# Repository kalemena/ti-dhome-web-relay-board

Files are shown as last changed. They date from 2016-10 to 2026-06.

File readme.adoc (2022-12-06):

= Web Relay Board
:toc:
:hardbreaks:

ifdef::env-github[]
:imagesdir: /
endif::[]

== Description

This project is an Open Source / Open Hardware minimal approach to build a Web Relay Board.
This Web Relay Board:

- allows to connect 16 devices allowing to switch on/off Main Power
- has temperature / humidity sensor
- captures Téléinfo (France Electricity provider serial consumption data)
- has REST API
- has Web Socket API

WARNING: Caution with 230v. Do not use high current.

Check more info in link:http://kalemena.github.io/ti-dhome-web-relay-board/[Details].

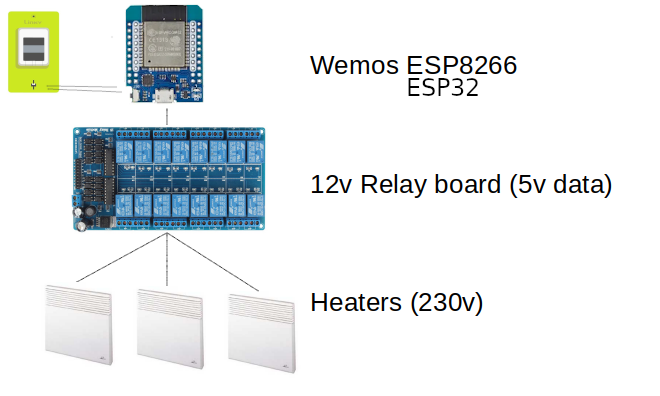
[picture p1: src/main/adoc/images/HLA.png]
HLA


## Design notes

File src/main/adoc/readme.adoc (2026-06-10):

:toc:

ifdef::env-github[]
:imagesdir: /src/main/adoc
endif::[]

= Web Relay Board

== Description

This project is an Open Source / Open Hardware minimal approach to build a Web Relay Board.

This Web Relay Board:

- allows to connect 16 devices allowing to switch on/off Main Power
- has temperature / humidity sensor
- captures Téléinfo (France Electricity provider serial consumption data)
- has REST API
- has Web Socket API

WARNING: Caution with 230v. Do not use high current.

The Web Relay board uses HTTP/REST API as interface.
Additionaly, simple Web UI is implemented on top of the REST API.

In practice, the Web Relay is used to manage electric heaters with data wire named link:http://www.planete-domotique.com/blog/2012/01/05/piloter-un-radiateur-grace-a-son-fil-pilote/[fil pilote] which is 230v at very low current. The heaters are ochestrated through Node-Red.

NOTE: This project is part of a wider link:https://github.com/kalemena/ti-dhome[TiDhome Home Automation] project.

.Integration WebRelay and Teleinfo
HLA

.Integration Teleinfo
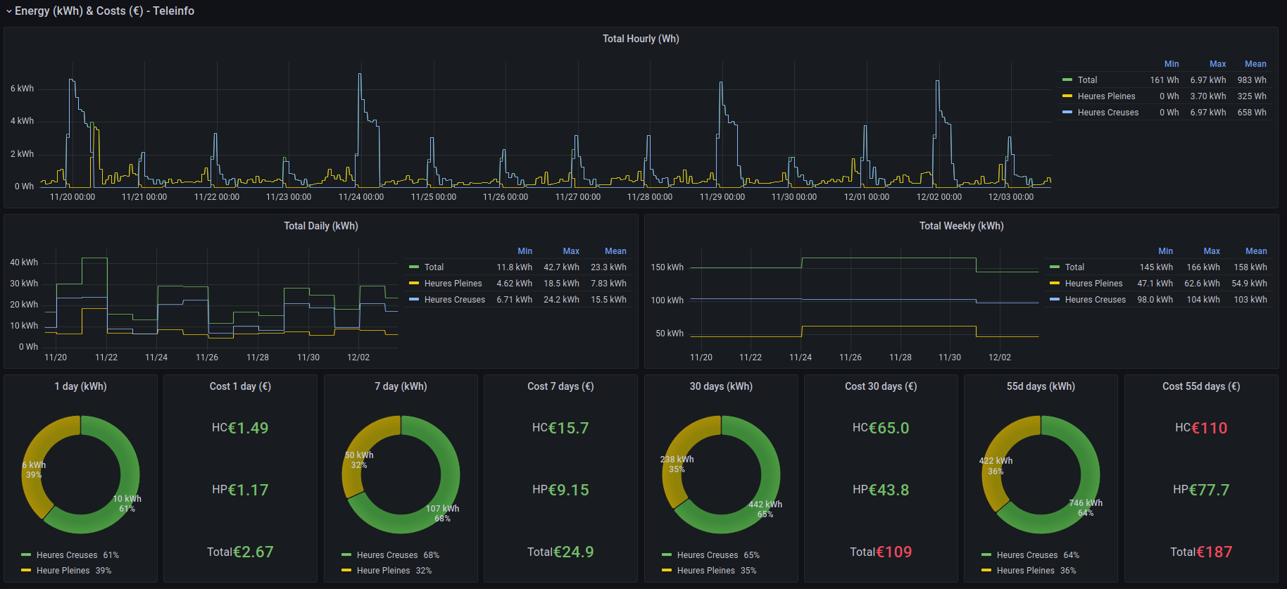
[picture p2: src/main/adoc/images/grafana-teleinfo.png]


NOTE: Above is an example of a dashboard created as part of Ti-Dhome project and using mostly Teleinfo data produces by the module in this repo, published to Node-Red through Web Sockets and inserted in Prometheus for Grafana use.

== Specifications

- 16 relays for 230v main current
- Wifi
- link:#api[REST API]
- WebSockets
- Reads EDF Téléinfo (France power consumption of the home as serial stream of data)
- Reads room temperature and humidity
- Simple web UI

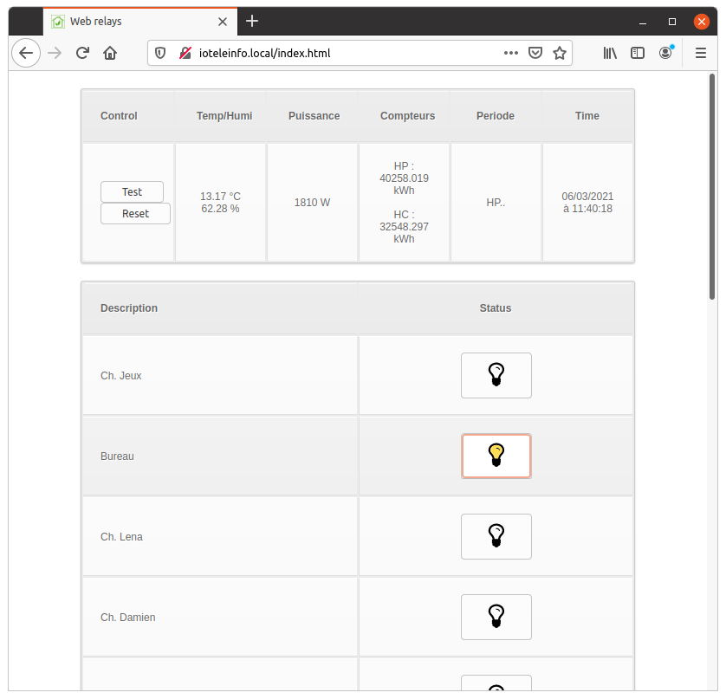
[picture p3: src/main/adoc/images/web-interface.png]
Web Relays UI


== PCB

PCB available at link:{giturl}/src/main/gerber[here]

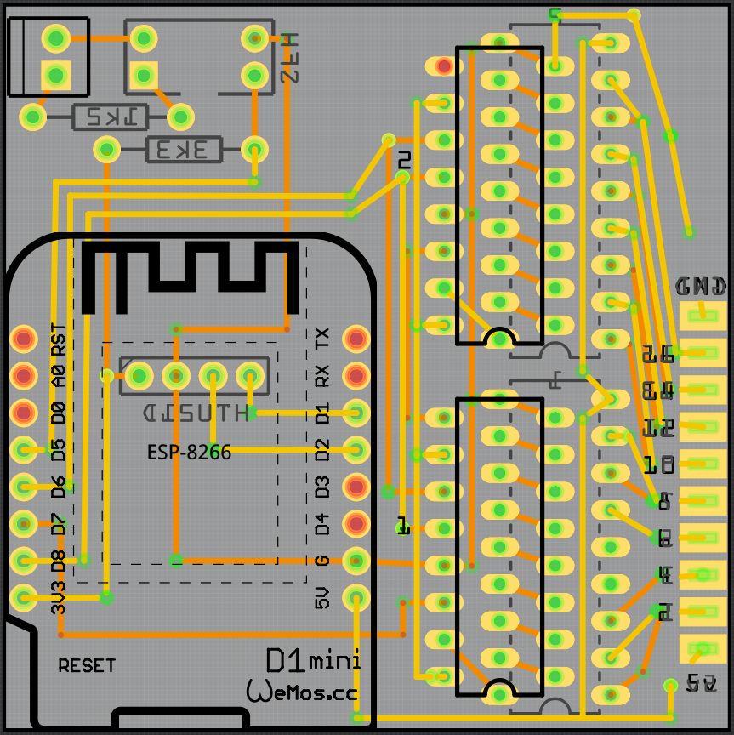
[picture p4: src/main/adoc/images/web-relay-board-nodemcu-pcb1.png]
PCB Board ESP8266 WeMos


PCB was printed at link:https://www.dfrobot.com/index.php?route=product/pcb&product_id=1351[DFRobot]

== Integration in Electric panel

Here is an integration of freshly solder PCB into electric panel:

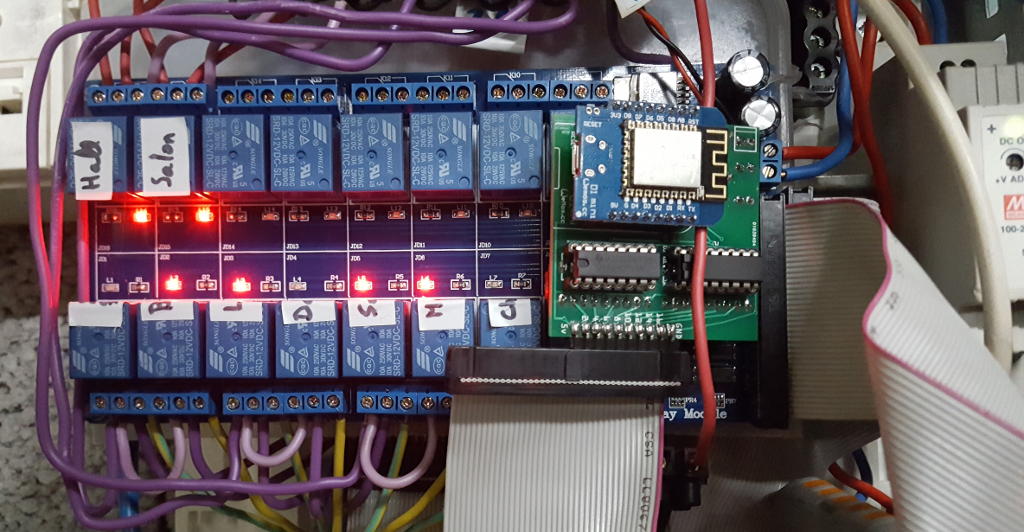
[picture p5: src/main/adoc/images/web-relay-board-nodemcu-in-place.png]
Electric panel Web Relays


== BOM

Here is list of items to purchase:

.BOM
[width="80%",cols="3,^2,10",options="header"]
|=========================================================
|Component |Price |Comment

| SainSmart 16 relays |~ 12€ | 16 relays 12v with 5v data triggers

| Wemos ESP8266 or ESP32 with (Wemos-clone pin layout)] |~ 4€ | 

| 2x 74HC595 |~ 0.2€ | Shift Register IC DIP-16 Texas (sold by 20)

| 2x ULN2803 |~ 0.12€ | (sold by 20)

| Optional (for Teleinfo and Temperature sensor | |

| SFH6206 | < 1€ | Optocoupler for Teleinfo
| 4.7k resistor | | For Teleinfo
| HTU21D | < 4€ | Temperature sensor

| *Total* | ~ 20€ |

|=========================================================

// GitHub - api
ifdef::env-github[]

link:api.adoc[API page] describes sample queries.

endif::[]

// non-GitHub - api
ifndef::env-github[]

:leveloffset: +1

include::api.adoc[API page]

:leveloffset: -1

endif::[]

== TODO

- create 3D-printed plastic box

// GitHub - iterations
ifdef::env-github[]

== Iterations

link:iterations.adoc[Here] are described step by step experiments to reach final product.

endif::[]

// non-GitHub - iterations
ifndef::env-github[]

:leveloffset: +1

include::iterations.adoc[Iterations page]

:leveloffset: -1

endif::[]

== Arduino CLI tips

```bash
% export BOARD=esp32:esp32:d1_mini32
% export SKETCH=./src/main/sketches/esp32-01-led/esp32-01-led.ino
% export PORT=/dev/cu.usbserial-110

% arduino-cli compile --fqbn ${BOARD} ${SKETCH} \
  && arduino-cli upload --fqbn ${BOARD} --port ${PORT} ${SKETCH}

% arduino-cli monitor --port ${PORT} --config baudrate=115200
```

== Links

Other interesting links for more specific heater oriented board:

* link:https://github.com/tducret/programmateur-fil-pilote-wifi/tree/master/Mat%C3%A9riel/1.3/Tutoriel[Programmateur-fil-pilote-wifi]

* link:https://air.imag.fr/index.php/Developing_IoT_Mashups_with_Docker,_MQTT,_Node-RED,_InfluxDB,_Grafana[IoT Mashups]

* link:https://telefab.fr/2013/11/10/controle-a-distance-des-radiateurs/[Contrôle à distance des radiateurs]

.Integration with Node-RED
* link:https://github.com/DenisMtfl/node-red-contrib-dynamic-thermostat[Node-Red Thermostat]
* link:https://github.com/naimo84/node-red-contrib-ical-events[iCal Events] or link:https://github.com/tyrrellsystems/node-red-contrib-simple-weekly-scheduler[Weekly scheduler]

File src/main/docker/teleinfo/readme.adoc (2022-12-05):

= Example - Teleinfo
:toc:
:hardbreaks:

This folder contains a sample demoing how to graph Teleinfo data.

Teleinfo is France EDF metrics of your home power consumption.

There are several types of information provided by Teleinfo:

- Live power: 
PAPP, etc

- Historical: 
Based on indexes, energy can be easily computed.
This however might depend on High/Low hours costs.
Costs is a simple computation of counter rate, multiplied by H/L costs.

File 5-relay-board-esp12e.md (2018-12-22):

## 5 - ESP8266 - 12E

Switch from NodeMCU to ESP12.

### Wiring

### Resources

http://arduino-er.blogspot.fr/2015/05/fit-esp-12-breakout-board-on-breadboard.html

http://myrobotlab.org/content/esp8266-12-series-wifi-modules-update-out-lua-arduino-ide

http://www.kloppenborg.net/blog/microcontrollers/2016/08/02/getting-started-with-the-esp8266

| NodeMCU | 74HC595 | Comment |
| --- |:---:|:---:|
| gpio13 (D7) | pin 14 | data |
| gpio14 (D5) | pin 11 | clock (both 74HC595) |
| gpio15 (D8) | pin 12 | latch (both 74HC595) |

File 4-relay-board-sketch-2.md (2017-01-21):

## 4 - Relay board sketch

[First sketch](3-relay-board-sketch.md) is not very efficient.

It only touched simple ESP8266 capability.

This iteration is about going deeper into the topic:
- host static files such as images or CSS files
- use the SPIFFS ~3MB flash storage
- better HTML rendering
- web sockets

### Steps

#### Un coup dans le 'SPIFFS'

To leverage most of the 4MB disk from ESP8266, install plugin:

[Arduino IDE SPIFFS plugin](https://github.com/esp8266/arduino-esp8266fs-plugin)

Usage is pretty simple:
- create subfolder from sketch folder named 'data'
- use Arduino IDE / Tools / ESP Sketch Data Upload
- this takes very long as it uploads ~ 3MB (no matter what)

#### Sketch details

The sketch can be found under [web-relay-advanced](sketches/esp8266-web-relay-advanced) folder.

This is a basic sketch from SPIFFS example, with addition of relay web services.

SPIFFS is used only to load SVG images to be displayed on URL /index.htm.

### Resources

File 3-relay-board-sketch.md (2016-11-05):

## 3 - Relay board sketch

Breadboard prototype done at [02 Relay Board Prototype](2-relay-board-prototype.md)

Now is time for a bit of coding.

### How-To

Here is the first [Basic sketch](sketches/esp8266-web-relay-wifi/esp8266-web-relay-wifi.ino)

Details of mathematics in next section.

Steps:
- Uploaded from Arduino IDE
- Open Arduino console
- This should log the URL with IP address to connect to Wifi device
- connect using browser to see the table where you can switch on and off the relays

### Mathematics

#### Binary computation

We have wired 16 outputs.

This in turns can be mapped to an integer from 0 to 65535.

In Arduino code, this means [__unsigned int__](https://www.arduino.cc/en/Reference/UnsignedInt).

Let's see what this means from [Byte mathematics](http://playground.arduino.cc/Code/BitMath#quickref)

```js
unsigned int relayState = 0;

// state of each relay (switchId is relay number from 0 to 15):
boolean switchState = ((relayState >> switchId) & 1);

// Set relay to 0:
relayState &= ~(1 << relayNb);

// Set relat to 1:
relayState |= (1 << relayNb);
```

#### 74HC595 - ShiftOut

The [74HC595 ShiftOut](https://www.arduino.cc/en/Reference/ShiftOut) states that it is 8 bit and requires two steps operation to shift bits.

```js
// Value is anything between 0 to 65535 representing 16 bits of data I/Os
void switchRelay(int value) 
{
   // take the latchPin low:
   digitalWrite(latchPin, LOW);

   // shift out the highbyte
   shiftOut(dataPin, clockPin, MSBFIRST, (value >> 8));
   // shift out the lowbyte
   shiftOut(dataPin, clockPin, MSBFIRST, value);

   //take the latch pin high so the LEDs will light up:
   digitalWrite(latchPin, HIGH);
}
```

### Resources

- [74HC595 ShiftOut](https://www.arduino.cc/en/Reference/ShiftOut)

- [Byte mathematics](http://playground.arduino.cc/Code/BitMath#quickref)

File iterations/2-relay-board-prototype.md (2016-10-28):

# Breadboard relay board

Using Node MCU for Wifi, there are few remaining constraints:

- GPIOs are 3.3v and we need 5v: __ULN2803__ to the rescue
> ULN2803 is a Darlington array which can be used to translate from 3.3v digital outputs to 5v

- Not enough GPIOs: __74HC595__ to the rescue
> This components enables use of 3 GPIOs to be used in serial protocol to handle in our case the 16 outputs requires for relay board

Photo (:bell: only relay 8 to 15):

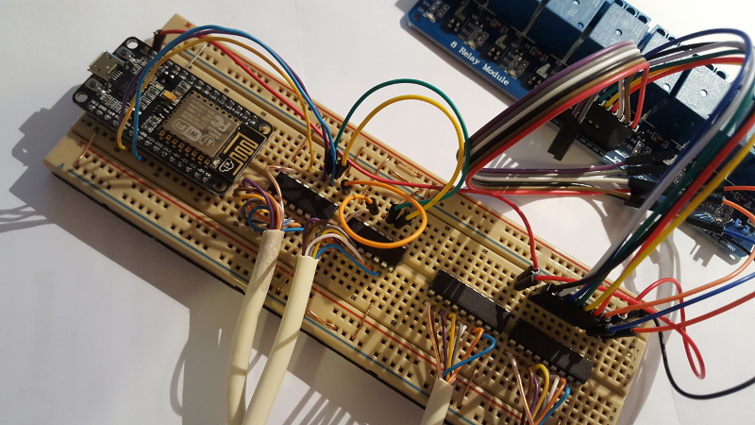
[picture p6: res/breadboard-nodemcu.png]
Breadboard NodeMCU


Fritzing picture:

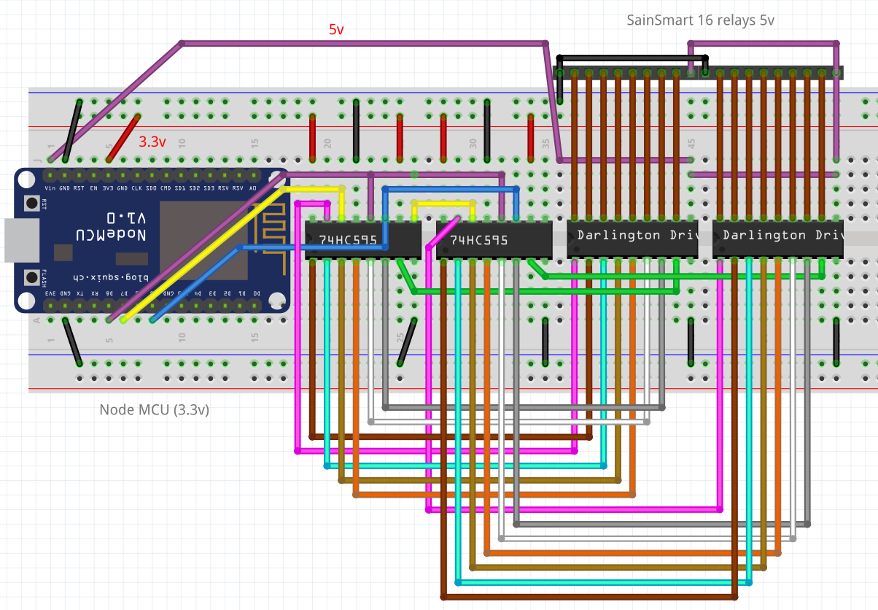
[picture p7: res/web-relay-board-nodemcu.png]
Breadboard NodeMCU


# Procedure

Few more details

## 74HC595

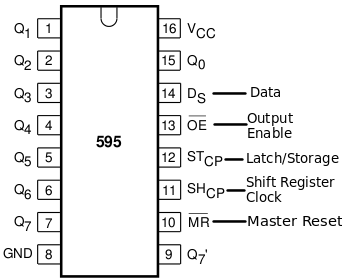
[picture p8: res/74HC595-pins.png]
74HC595 pins


We will use 3 pins from Node MCU:

| NodeMCU | 74HC595 | Comment  |
| --- |:---:|:---:|
| gpio13 (D7) | pin 14 | data |
| gpio14 (D5) | pin 11 | clock (both 74HC595) |
| gpio15 (D8) | pin 12 | latch (both 74HC595) |

:bell: Ground and 3.3v plugged obviously.

:bell: 1st 74HC595 is connected to 2nd 74HC595 from pin 9 to pin 14.

__We now have 16 I/Os !__

## ULN2803

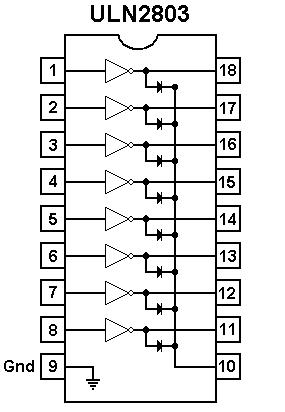
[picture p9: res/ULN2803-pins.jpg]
ULN2803 pins


| 74HC595 | ULN2803 | Comment  |
| --- |:---:|:---:|
| 8 | 9 | Ground |
| 5v (from power supply) | 10 | 5v :bell: not the 3.3v here!  |
| Q0 to Q7 | 1 to 8 | Outputs |

# Resources

- [ESP8266 8x8 matrix](http://www.instructables.com/id/NODEMCU-LUA-ESP8266-With-74HC595-LED-and-Matrix-Dr/step2/ESP8266-driving-dual-595s-with-8-x-8-Matrix/)

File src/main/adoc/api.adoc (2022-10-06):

= API
:toc:
:hardbreaks:

[TIP]
====
REST API and websocket API are returning same JSON structure data.

Additionaly, websocket will periodically push changing info such as other user relay switch, Téléinfo and temperature.
====

Below is API description with examples:

== GET /

Main HTML page display simple button and status:

Web Relays UI

== GET /status

[source, json]
----
$ curl http://ioteleinfo.local/status | jq .

{
  "system": {
    "chip-model": "ESP32-D0WDQ6",
    "chip-revision": 1,
    "chip-cores": 2,
    "chip-bluetooth": "/BT/BLE",
    "chip-id": "ABCDEFGH",
    "heap": 256412,
    "flash-size": 4,
    "flash-type": "external",
    "time-iso": "2021-02-06T11:44:37Z"
  },
  "sensors": {
    "temperature": 13.12,
    "humidity": 62.5
  },
  "relays": [
    {
      "description": "Ch. Jeux",
      "id": 0,
      "value": 0
    },
    {
      "description": "Bureau",
      "id": 1,
      "value": 0
    },
    ...
    {
      "description": "Hall",
      "id": 15,
      "value": 0
    }
  ],
  "teleinfo": {
    "ADCO": 123456789,
    "OPTARIF": "HC..",
    "ISOUSC": 45,
    "HCHC": 32548297,
    "HCHP": 40260054,
    "PTEC": "HP..",
    "IINST": 5,
    "IMAX": 90,
    "PAPP": 1100,
    "HHPHC": "A",
    "MOTDETAT": 0
  },
  "message": "status"
}
----

== GET /relays/set?id=X&value=Y

Specify id between 0 and 15:

[source, bash]
----
$ curl -v http://ioteleinfo.local/relays/set?id=1&value=-1
{
   "id": 1, "value":0
}
----

TIP: value is 0, 1 or -1 to switch blindly 

== GET /test

Triggers a cycle on/off on each of the relays, with 500ms in between on/off.
Useful to test the websocket reaction of Web UI.

[source, bash]
----
$ curl -v http://ioteleinfo.local/test
----

== WebSocket

Example at link:/src/main/sketches/esp32-10-web-relay-th-teleinfo/data/index.html[index.html]

.Time events (from time to time)
[source, json]
----
{
    "system":{
        "time":"1615034255"
    }
}
----

.Teleinfo events (when some field changes)
[source, json]
----
{
    "teleinfo":{
        "PAPP":"01140"
    }
}
----

.Temperature events (from time to time)
[source, json]
----
{
    "sensors":{
        "temperature":13.2,
        "humidity":62.75
    }
}
----

.Relays events (when a switch changes)
[source, json]
----
{
    "relays":[
        {"id":2,"value":1}
    ]
}
----

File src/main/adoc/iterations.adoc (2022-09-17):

= Iterations
:toc:

== 0 - Manual Setup ESP8266 board in Arduino IDE

NOTE: Since this tutorial was written, I made available a link:https://github.com/kalemena/iot-tools[Docker Arduino IDE]

The development uses simple Arduino IDE with ESP8266 libs.

Follow this guide to setup ESP8266 board in Arduino IDE: link:https://github.com/esp8266/Arduino[]

Documentation is here: link:http://esp8266.github.io/Arduino/versions/2.3.0/[]

=== Procedure

- Import ESP Board into Arduino IDE

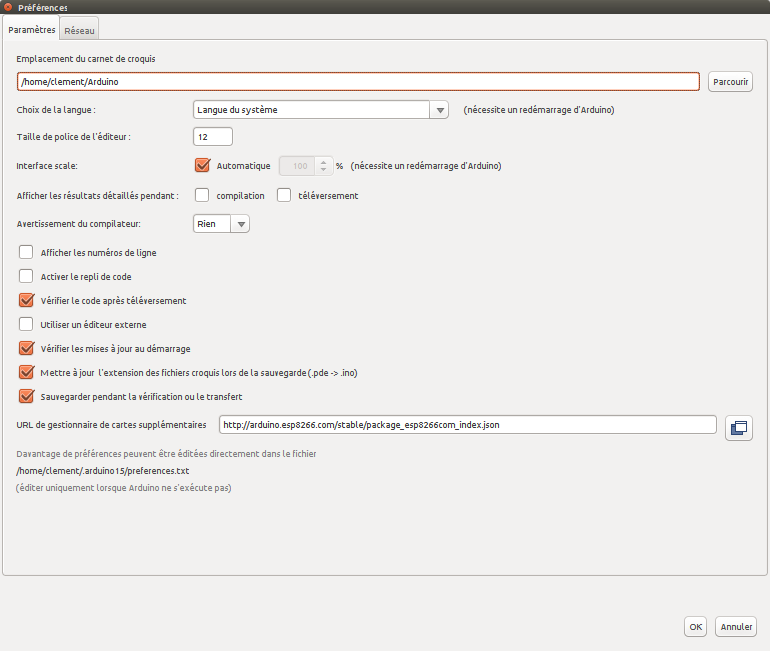
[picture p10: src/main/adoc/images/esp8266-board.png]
Import ESP Boards


- Load the Libraries for ESP8266

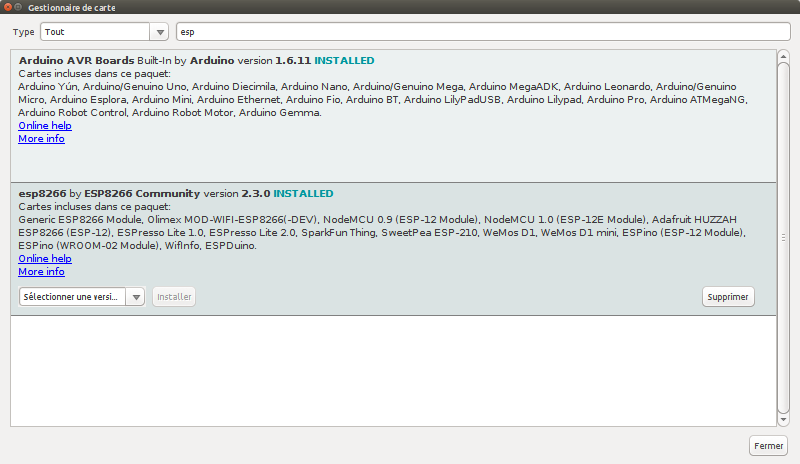
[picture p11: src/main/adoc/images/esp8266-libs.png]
Load ESP libraries


- Load sample *hello* app into NodeMCU

In Arduino IDE, select proper board, example:
- Tools/Cards/NodeMCU 1.0 board
- CPU 160 MHz
- <correct USB device>

Create sketch such as the link:{giturl}/src/main/sketches/esp8266-01-led/esp8266-01-led.ino[ESP8266 LED]

```js
void setup() {
  // initialize digital pin 2 as an output.
  pinMode(2, OUTPUT);
}

// the loop function runs over and over again forever
void loop() {
  digitalWrite(2, HIGH);   // turn the LED on (HIGH is the voltage level)
  delay(1000);              // wait for a second
  digitalWrite(2, LOW);    // turn the LED off by making the voltage LOW
  delay(1000);              // wait for a second
}
```

LED should blink as shown below:

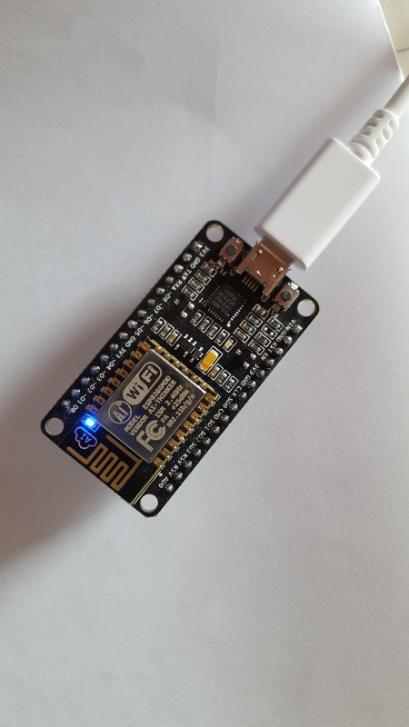
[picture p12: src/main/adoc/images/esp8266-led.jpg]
NodeMCU Blink


* Control a Wifi LED
** Upload sketch found at link:{giturl}/src/main/sketches/esp8266-02-led-wifi/esp8266-02-led-wifi.ino[ESP8266 LED WIFI] with changing Wifi network settings
** Open Serial Consoleon Arduino IDE
** Ensure from logs that NodeMCU connected to local Wifi
** Browse to IP address logged out
** Click on button to switch led On and Off

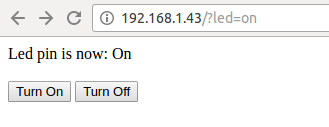
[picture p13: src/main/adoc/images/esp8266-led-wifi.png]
NodeMCU Blink Wifi


=== Resources

link:https://kalemena.github.io/iot-tools/[Arduino/ESP8266/ESP32 Pin Layout]

== 1 - Docker Setup ESP8266 board in Arduino IDE

See link:https://github.com/kalemena/iot-tools[Docker image kalemena:arduino:latest]

* check your tty device. e.g. /dev/ttyUSB2 and match it in *Makefile*
* open the Arduino IDE with:

[source,bash]
----
$ make arduino
----

== 2 - Breadboard relay board

Breadboard video

Using Node MCU for Wifi, there are few remaining constraints:

- GPIOs are 3.3v and we need 5v: *ULN2803* to the rescue
    
    > ULN2803 is a Darlington array which can be used to translate from 3.3v digital outputs to 5v

- Not enough GPIOs: *74HC595* to the rescue
    
    > This components enables use of 3 GPIOs to be used in serial protocol to handle in our case the 16 outputs requires for relay board

Photo (showing wired relay 8 to 15):

Breadboard NodeMCU

Fritzing picture:

Breadboard NodeMCU

=== Procedure

Few more details

==== 74HC595

74HC595 pins

We will use 3 pins from Node MCU:

.wiring 74HC595
[width="80%",cols="3,^2,10",options="header"]
|=========================================================
|NodeMCU |74HC595 |Comment

| gpio13 (D7)   | pin 14        | data
| gpio14 (D5)   | pin 11        | clock (both 74HC595) 
| gpio15 (D8)   | pin 12        | latch (both 74HC595) 

|=========================================================

IMPORTANT: Ground and 3.3v plugged obviously.

IMPORTANT: 1st 74HC595 is connected to 2nd 74HC595 from pin 9 to pin 14.

NOTE: *We now have 16 I/Os through 3 ESP8266 pins!*

==== ULN2803

ULN2803 pins

.wiring ULN2803
[width="80%",cols="3,^2,10",options="header"]
|=========================================================
|74HC595 |ULN2803 |Comment

| 8    | 9         | Ground
| 5v (from power supply)   | 10        | *5v not the 3.3v here!*
| Q0 to Q7   | 1 to 8        | Outputs

|=========================================================

=== Resources

- link:http://www.instructables.com/id/NODEMCU-LUA-ESP8266-With-74HC595-LED-and-Matrix-Dr/step2/ESP8266-driving-dual-595s-with-8-x-8-Matrix/[ESP8266 8x8 matrix]

== 3 - Relay board sketch

Now is time for a bit of coding.

=== How-To

Here is the first link:{giturl}/src/main/sketches/esp8266-04-web-relay-wifi/esp8266-04-web-relay-wifi.ino[Basic sketch]

Details of mathematics in next section.

Steps:

- Uploaded from Arduino IDE
- Open Arduino console
- This should log the URL with IP address to connect to Wifi device
- Connect using browser to see the table where you can switch on and off the relays

=== Mathematics

==== Binary computation

We have wired 16 outputs.

The outputs can be mapped to an integer from 0 to 65535.

In Arduino code, this means link:https://www.arduino.cc/en/Reference/UnsignedInt[__unsigned int__]

Let's see what this means from link:http://playground.arduino.cc/Code/BitMath#quickref[Byte mathematics]

```js
unsigned int relayState = 0;

// state of each relay (switchId is relay number from 0 to 15):
boolean switchState = ((relayState >> switchId) & 1);

// Set relay to 0:
relayState &= ~(1 << relayNb);

// Set relat to 1:
relayState |= (1 << relayNb);
```

==== 74HC595 - ShiftOut

The link:https://www.arduino.cc/en/Reference/ShiftOut[74HC595 ShiftOut] states that it is 8 bit and requires two steps operation to shift bits.

```js
// Value is anything between 0 to 65535 representing 16 bits of data I/Os
void switchRelay(int value) 
{
   // take the latchPin low:
   digitalWrite(latchPin, LOW);

   // shift out the highbyte
   shiftOut(dataPin, clockPin, MSBFIRST, (value >> 8));
   // shift out the lowbyte
   shiftOut(dataPin, clockPin, MSBFIRST, value);

   //take the latch pin high so the LEDs will light up:
   digitalWrite(latchPin, HIGH);
}
```

== 4 - Relay board sketch

This iteration is about going deeper into the topic:

- host static files such as images or CSS files
- use the SPIFFS ~3MB flash storage
- better HTML rendering
- web sockets

=== Steps

==== Un coup dans le 'SPIFFS'

To leverage most of the 4MB disk from ESP8266, install plugin:

link:https://github.com/esp8266/arduino-esp8266fs-plugin[Arduino IDE SPIFFS plugin]

Usage is pretty simple:

- create subfolder from sketch folder named 'data'
- use Arduino IDE / Tools / ESP Sketch Data Upload
- this takes very long as it uploads ~ 3MB (no matter what)

==== Sketch details

The sketch can be found under link:{giturl}/src/main/sketches/esp8266-05-web-relay-advanced[web-relay-advanced] folder.

This is a basic sketch from SPIFFS example, with addition of relay web services.

SPIFFS is used only to load SVG images to be displayed on URL /index.htm.

== 5 - ESP8266 - 12E

Switch from NodeMCU to ESP12.

WARNING: This is aborted story, but it was interesting study! Instead ESP32 might be of better interest.

=== Resources

* link:http://arduino-er.blogspot.fr/2015/05/fit-esp-12-breakout-board-on-breadboard.html[]
* link:http://myrobotlab.org/content/esp8266-12-series-wifi-modules-update-out-lua-arduino-ide[]

== 6 - PCB based on NodeMCU WeMos

PCB sample details link:dist[here]

PCB Board ESP8266 WeMos

PCB was printed at link:https://www.dfrobot.com/index.php?route=product/pcb&product_id=1351[DFRobot]

=== PCB - Fritzing

PCB was done using fritzing, the lazy way.

WARNING: Auto-routing did not work (as often) so all is routed manually.

See link:https://fritzing.org/home/[Fritzing]

Fritzing project can be found link:https://github.com/kalemena/ti-dhome-web-relay-board/blob/master/web-relay-board-nodemcu.fzz[here]

== 7 - WebSocket

Adding WebSocket code for Arduino and Web UI.

Also updated SPIFFS to LittleFS.

[TIP]
====
To test, +
- open Web UI at http://iotrelays.local/ +
- *curl http://iotrelays.local/test 

This initiate the rolling on/off test on each relay one by one. +
The UI should move according to relay current state because it receives web socket events.
====

* link:{giturl}/src/main/sketches/esp8266-07-web-relay-web-socket/esp8266-07-web-relay-web-socket.ino[Sketch]
* link:{giturl}/src/main/sketches/esp8266-07-web-relay-web-socket/data/index.html[Web UI]

== 8 - T/H and Teleinfo

Adding Sensors Temperature, Humidity and France Power (Teleinfo).

The board created in previous iterations supports a T/H sensor HTU21 and the components required for Teleinfo.

Examples:

* link:https://github.com/kalemena/iot-tools/blob/master/src/main/sketches/esp8266-htu21d-test/esp8266-htu21d-test.ino[Example HTU21S]
* link:https://github.com/kalemena/iot-tools/blob/master/src/main/sketches/teleinfo/teleinfo.ino[Example Téléinfo]

Complete sources:

* link:{giturl}/src/main/sketches/esp32-10-web-relay-th-teleinfo/esp32-10-web-relay-th-teleinfo.ino[Sketch]
* link:{giturl}/src/main/sketches/esp32-10-web-relay-th-teleinfo/data/index.html[Web UI]

.Wiring Teleinfo
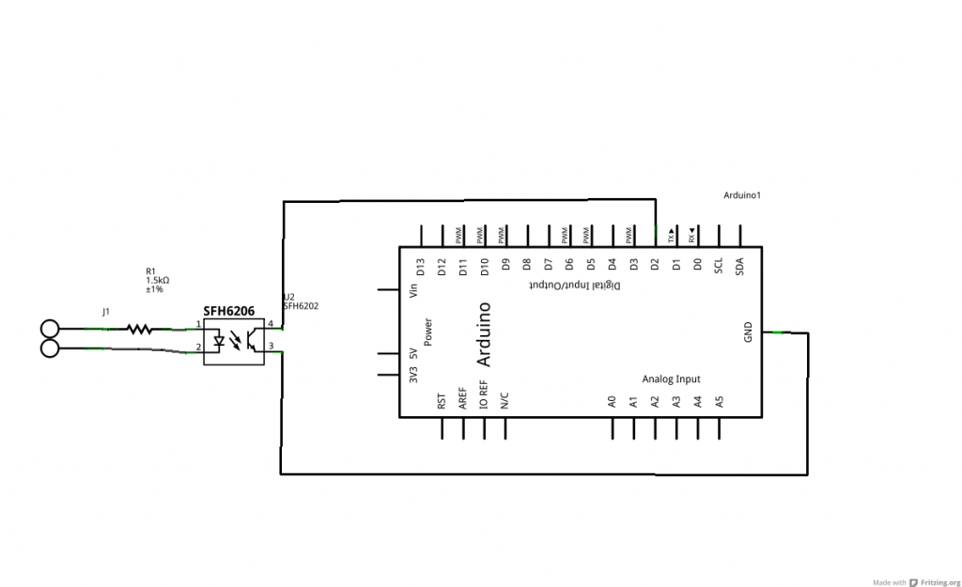
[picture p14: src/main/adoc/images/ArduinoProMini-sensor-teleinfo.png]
Teleinfo


=== References

* link:https://particulier.edf.fr/content/dam/2-Actifs/Documents/Offres/Grille_prix_Tarif_Bleu.pdf[Cost EDF]
* link:https://github.com/hallard/LibTeleinfo/blob/master/examples/Wifinfo/Wifinfo.ino[Hallard LibTeleinfo]

== 9 - ESP 32

Switching to ESP32 with same form factor as Wemos D1 mini.

ESP 32 pins

Main differences with Wemos ESP8266:

* Pins are slightly different, but can fit previously created PCB without soldering
* ESP32 system info
* Wifi and WebServer libs don't allow same port WebSocket
* SoftwareSerial is replaced with HardwareSerial
* Web UI is enhanced to allow continuous update of power and temperature sensor

Complete sources:

* link:{giturl}/src/main/sketches/esp32-10-web-relay-th-teleinfo/esp32-10-web-relay-th-teleinfo.ino[Sketch]
* link:{giturl}/src/main/sketches/esp32-10-web-relay-th-teleinfo/data/index.html[Web UI]

== 10 - Wiring the Heaters using Fil Pilote

This is high-level schema to wire the relays onto the heaters and perform on/off/low heat actions.

.Fil Pilote wiring schema:
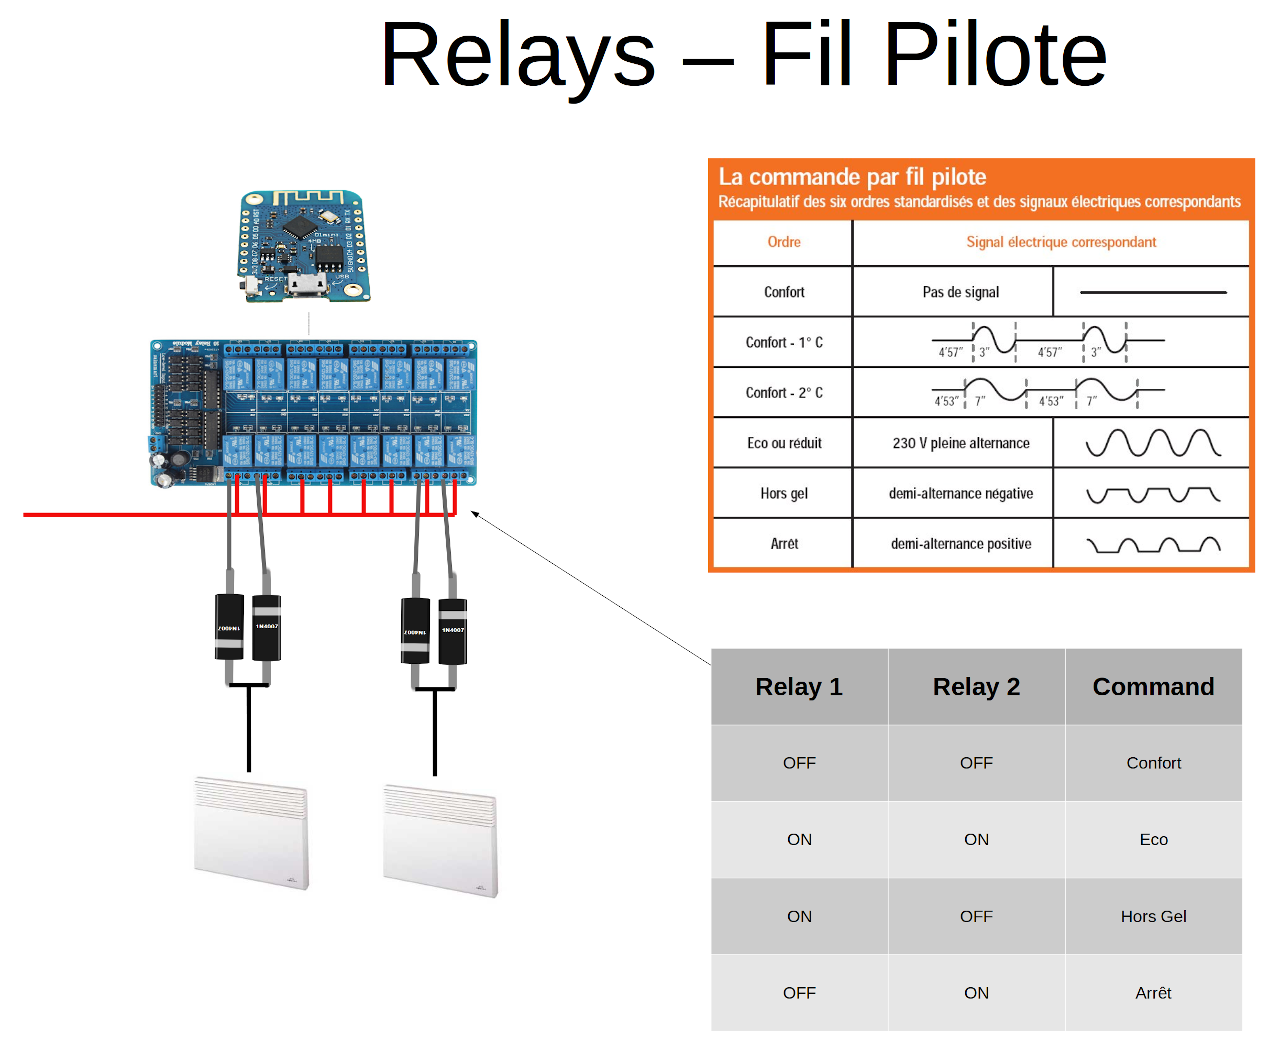
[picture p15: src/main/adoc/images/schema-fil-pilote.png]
Fil Pilote


== References

* link:https://arduinojson.org/v6/assistant/[JSON Assistant]

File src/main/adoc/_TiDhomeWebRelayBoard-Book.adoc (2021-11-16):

:author: Kalemena
:library: Asciidoctor
:encoding: utf-8
:idprefix:
:numbered:
:rootdir: /project/src/main/adoc
:imagesdir: {rootdir}/images
:giturl: https://github.com/kalemena/ti-dhome-web-relay-board/tree/master
:binariesdir: https://github.com/kalemena/ti-dhome-web-relay-board/raw/master/src/main/adoc/binaries
:assetsdir: https://github.com/kalemena/ti-dhome-web-relay-board/raw/master/src/main/adoc/assets
//:toc: left
:toclevels: 5
//:toc-placement: left
:css-signature: demo
:doctype: book
:icons: font
:icon-set: octicon
//:stylesheet: {rootdir}/themes/asciidoctor.css
:title-page: TiDhome Web Relay Board
:title-logo-image: {rootdir}/images/favicon.png
//:favicon: {rootdir}/images/favicon.png
//:front-cover-image: 
:pagenums:

:description: TiDhome Web Relay Board Project - Book

:toc:
:hardbreaks:

ifdef::backend-pdf[]
IMPORTANT: This is an automatically generated document written using AsciiDoc.
endif::[]

include::readme.adoc[General Info]

// <<<
// :leveloffset: +1
// include::includes/_cross-references.adoc[]

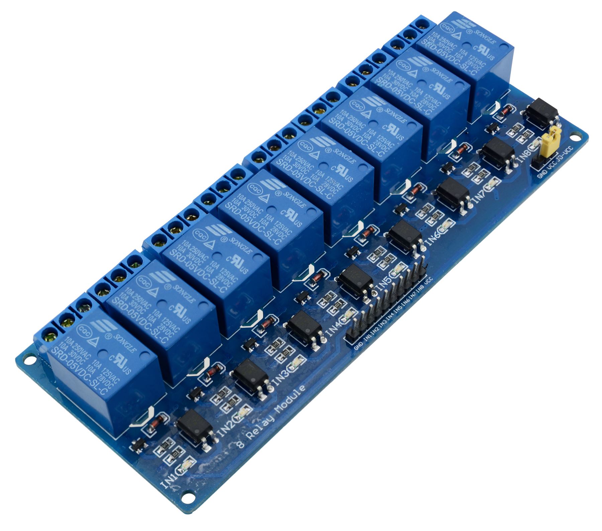
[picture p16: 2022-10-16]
src/main/adoc/images/sainsmart-8-channel-relay.jpg

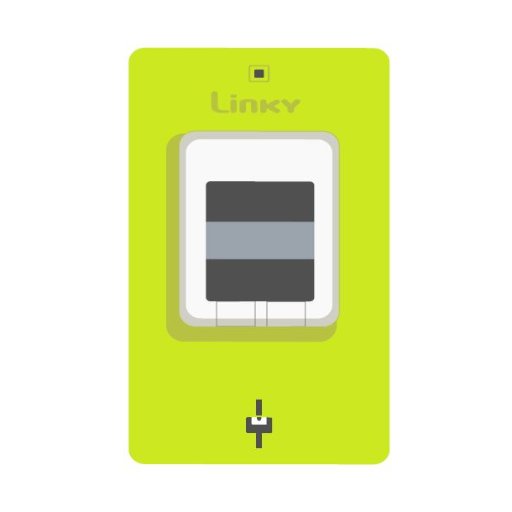
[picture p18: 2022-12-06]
src/main/adoc/images/linky.jpg

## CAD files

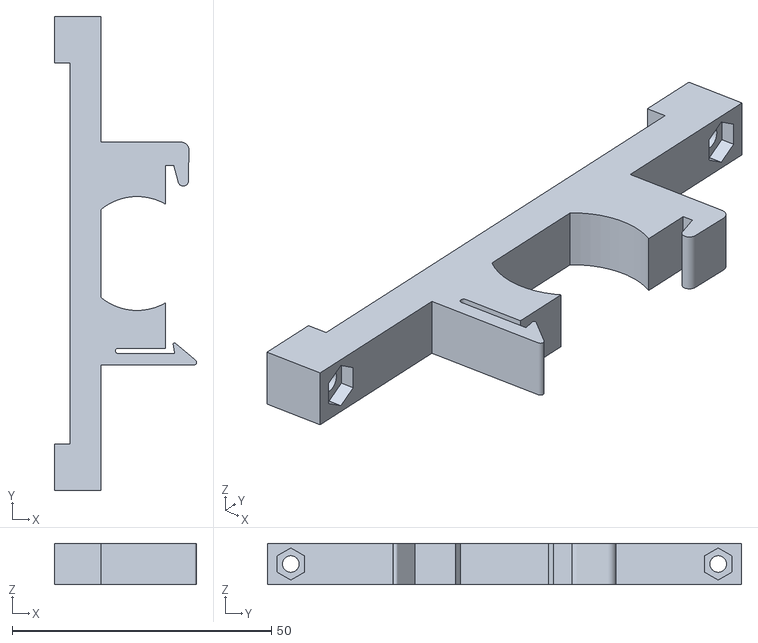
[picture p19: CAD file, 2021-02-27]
src/main/scad/web-relay-din-clip.stl
27.5 x 91.5 x 8.00

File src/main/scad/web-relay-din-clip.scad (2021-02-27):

$fn=50;

// Clip thickness
DIN_CLIP_W = 8;

module din_clip() {
    union() {
        difference() {
            cube([16,43,DIN_CLIP_W], center=true);
            hull() {
                translate([9,-18.8,0]) cylinder(d=1,h=DIN_CLIP_W+0.1,center=true);
                translate([-3.7,-18.8,0]) cylinder(d=1,h=DIN_CLIP_W+0.1,center=true);
            }
            translate([7,-1,0]) cube([3,36,DIN_CLIP_W+0.1],center=true);
            cylinder(d=22,h=DIN_CLIP_W+0.1,center=true);
        }
        hull() {
            translate([11,-21,0]) cylinder(d=1,h=DIN_CLIP_W,center=true);
            translate([8,-21,0]) cylinder(d=1,h=DIN_CLIP_W,center=true);
            translate([7.2,-17.5,0]) cylinder(d=0.5,h=DIN_CLIP_W,center=true);
        }
        hull() {
            translate([8.5,20,0]) cylinder(d=3,h=DIN_CLIP_W,center=true);
            translate([7.8,20,0]) cylinder(d=3,h=DIN_CLIP_W,center=true);
            translate([8.9,14,0]) cylinder(d=2,h=DIN_CLIP_W,center=true);
        }
    }
}

module din_relay_board() {
    difference() {
        union() {
            din_clip();
            translate([-10,0,0]) cube([6,90,DIN_CLIP_W], center=true);
            translate([-11.5,-82.5/2,0]) cube([9,9,DIN_CLIP_W], center=true);
            translate([-11.5,+82.5/2,0]) cube([9,9,DIN_CLIP_W], center=true);
        }
        
        translate([-10,-82.5/2,0]) rotate([0,90,0]) cylinder(d=3.2,h=15,center=true);
        translate([-10,+82.5/2,0]) rotate([0,90,0]) cylinder(d=3.2,h=15,center=true);
        
        translate([-4,-82.5/2,0]) rotate([0,90,0]) cylinder(d=6.2,h=10,center=true, $fn=6);
        translate([-4,+82.5/2,0]) rotate([0,90,0]) cylinder(d=6.2,h=10,center=true, $fn=6);
    }
}

din_relay_board();

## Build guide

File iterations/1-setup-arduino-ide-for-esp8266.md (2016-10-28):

# Installation

We want the development to be as simple as possible, leveraging Arduino IDE.

Follow this guide to setup ESP8266 board in Arduino IDE: https://github.com/esp8266/Arduino

Documentation is here: http://esp8266.github.io/Arduino/versions/2.3.0/

# Procedure

- Import ESP Board into Arduino IDE

Import ESP Boards

- Load the Libraries for ESP8266

Load ESP libraries

- Load sample _hello_ app into NodeMCU

In Arduino IDE, select proper board, example:
- Tools/Cards/NodeMCU 1.0 board
- CPU 160 MHz
- <correct USB device>

Create sketch such as the [ESP8266 LED](/sketches/esp8266-led/esp8266-led.ino)

```js
void setup() {
  // initialize digital pin 2 as an output.
  pinMode(2, OUTPUT);
}

// the loop function runs over and over again forever
void loop() {
  digitalWrite(2, HIGH);   // turn the LED on (HIGH is the voltage level)
  delay(1000);              // wait for a second
  digitalWrite(2, LOW);    // turn the LED off by making the voltage LOW
  delay(1000);              // wait for a second
}
```

LED should blink as shown below:

NodeMCU Blink

- Control a Wifi LED

 - Upload sketch found at [ESP8266 LED WIFI](/sketches/esp8266-led-wifi/esp8266-led-wifi.ino) with changing Wifi network settings
 - Open Serial Consoleon Arduino IDE
 - Ensure from logs that NodeMCU connected to local Wifi
 - Browse to IP address logged out
 - Click on button to switch led On and Off

NodeMCU Blink Wifi

# Resources

## Node MCU Pin Layout

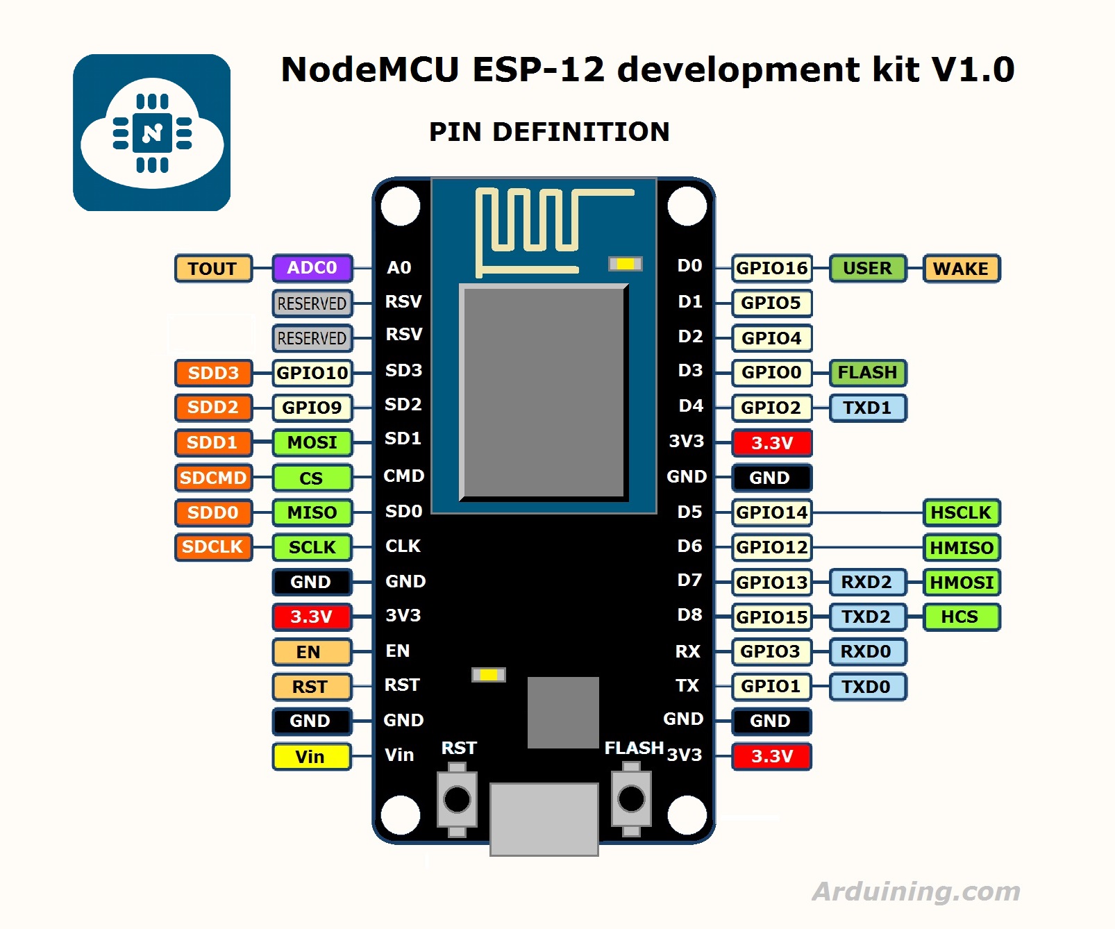
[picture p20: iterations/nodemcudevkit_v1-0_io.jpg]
Node MCU Pin Layout


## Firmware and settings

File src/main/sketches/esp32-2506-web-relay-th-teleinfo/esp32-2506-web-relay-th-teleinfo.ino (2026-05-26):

/* 
  ti-dhome - esp32 base web relay board
  Copyright (c) 2022 Kalemena. All rights reserved.

  access the sample web page at http://iotrelays.local
  edit the page by going to http://iotrelays.local/edit
*/

#include <Arduino.h>
#include "FS.h"
#include "LittleFS.h"

#include "time.h"

#include <ArduinoJson.h>

#include <ESPmDNS.h>
#include <WiFi.h>
#include <WebServer.h>
#include <WebSocketsServer.h>
#include "esp_chip_info.h"
WebServer server(80);
WebSocketsServer webSocket = WebSocketsServer(81);

// System
String chipId;
esp_chip_info_t chip_info;
unsigned long epochTime; 

// HTU21
#include <Wire.h>
#include "Adafruit_HTU21DF.h"
Adafruit_HTU21DF htu = Adafruit_HTU21DF();
float lastTemperature = 0.0;
float lastHumidity = 0.0;
boolean isHTU21Found = false;

// Relays
// holds 16 bits
unsigned int relayState = 0;

// Teleinfo
#include <LibTeleinfo.h>
HardwareSerial TeleInfo(2);  // Teleinfo Serial UART1/Serial2 pins 16,17
TInfo          tinfo;        // Teleinfo object

// ===== LOGGING
#define LOG_NONE  0
#define LOG_ERROR 1
#define LOG_WARN  2
#define LOG_INFO  3
#define LOG_DEBUG 4

#ifndef LOG_LEVEL
#define LOG_LEVEL LOG_DEBUG
#endif

#define LOGE(fmt, ...)  Serial.printf("[E] " fmt "\n", ##__VA_ARGS__)
#define LOGW(fmt, ...)  Serial.printf("[W] " fmt "\n", ##__VA_ARGS__)
#define LOGI(fmt, ...)  Serial.printf("[I] " fmt "\n", ##__VA_ARGS__)
#if LOG_LEVEL >= LOG_DEBUG
#define LOGD(fmt, ...)  Serial.printf("[D] " fmt "\n", ##__VA_ARGS__)
#define LOGD_RAW(x)     Serial.print(x)
#define LOGD_RAWLN(x)   Serial.println(x)
#else
#define LOGD(fmt, ...)
#define LOGD_RAW(x)
#define LOGD_RAWLN(x)
#endif

// ===== CONFIGURATION

#if __has_include("secrets.h")
#include "secrets.h"
#endif

#include "settings.h"

// ===== SETUP

void setup() {
  Serial.begin(115200);
  Serial.setDebugOutput(true);

  Serial.println();
  LOGI("Initializing ...");
  Serial.println();

  delay(100);

  // ===== System
  chipId = String((uint32_t)ESP.getEfuseMac(), HEX);
  chipId.toUpperCase();
  esp_chip_info(&chip_info);

  //init and get the time
  configTime(gmtOffset_sec, daylightOffset_sec, ntpServer);

  delay(100);

  // ===== File System
  if(!LittleFS.begin(false)){
    LOGE("LittleFS Mount Failed");
    return;
  } else {
    LOGI("LittleFS Mount OK");
  }
  listDir(LittleFS, "/", 3);

  delay(100);

  // ===== Teleinfo
  //TeleInfo.begin(1200);               // standard pins 16,17 
  TeleInfo.begin(1200, SERIAL_8N1, 18); // custom pins 18,17
  tinfo.init();
  tinfo.attachADPS(ADPSCallback);
  tinfo.attachData(DataCallback);
  tinfo.attachNewFrame(NewFrame);
  tinfo.attachUpdatedFrame(UpdatedFrame);

  delay(100);

  // ===== HTU21D
  int i = 0;
  while(i < 3) {
    i++;
    if(!isHTU21Found) {
      if(!htu.begin()) {
        LOGW("Couldn't find sensor ...");
        delay(100);
      } else {
        isHTU21Found = true;
        LOGI("HTU21D Sensor found !");
      }
    }
  }

  delay(100);

  // ===== Relays on 74HC595
  // Set pins to output so you can control the shift register
  pinMode(latchPin, OUTPUT);
  pinMode(clockPin, OUTPUT);
  pinMode(dataPin, OUTPUT);
  // reset to 0
  operation_relay_set_internal(0);

  delay(100);

  // ===== WiFi
  LOGI("===========");
  LOGI("Connecting to %s", ssid);
  WiFi.begin(ssid, password);
  while (WiFi.status() != WL_CONNECTED) {
    delay(500);
    Serial.print(".");
  }
  Serial.println("");
  LOGI("WiFi connected.");
  LOGI("IP address: %s", WiFi.localIP().toString().c_str());

  // ===== Controllers
  server.on("/", []() {
      // send index.html
      server.send(200, "text/html", "<html><head><meta http-equiv=\"refresh\" content=\"0; URL=/index.html\" /></head></html>");
  });
  server.on("/status", HTTP_GET, controller_status);
  server.on("/test", HTTP_GET, controller_test);
  server.on("/relays/set", HTTP_GET, controller_relay_set);
  server.on("/metrics", HTTP_GET, controller_metrics);
  server.onNotFound(controller_handleNotFound); 

  // ===== mDNS
  if(!MDNS.begin(host)) {
     LOGE("Error starting mDNS");
     return;
  }
  // Add service to mDNS
  MDNS.addService("http", "tcp", 80);

  // ===== Listen
  webSocket.begin();
  webSocket.onEvent(websocket_event);
  server.begin();
}

void loop(){
  // Teleinfo - drain full UART buffer to avoid byte loss
  while (TeleInfo.available()) {
    tinfo.process(TeleInfo.read());
  }
  
  // WiFi reconnect
  static unsigned long lastWifiCheck = 0;
  if (WiFi.status() != WL_CONNECTED) {
    if (millis() - lastWifiCheck > 5000) {
      LOGW("WiFi disconnected, reconnecting...");
      WiFi.reconnect();
      lastWifiCheck = millis();
    }
  }

  if (WiFi.status() == WL_CONNECTED) {
    static bool mdnsReady = false;
    if (!mdnsReady && MDNS.begin(host)) {
      MDNS.addService("http", "tcp", 80);
      mdnsReady = true;
      LOGI("mDNS restarted");
    }
  }
  
  server.handleClient();
  webSocket.loop(); 
}

// ===== TOOLS

void hexdump(const void *mem, uint32_t len, uint8_t cols = 16) {
  const uint8_t* src = (const uint8_t*) mem;
  Serial.printf("\n[HEXDUMP] Address: 0x%08X len: 0x%X (%d)", (ptrdiff_t)src, len, len);
  for(uint32_t i = 0; i < len; i++) {
    if(i % cols == 0) {
      Serial.printf("\n[0x%08X] 0x%08X: ", (ptrdiff_t)src, i);
    }
    Serial.printf("%02X ", *src);
    src++;
  }
  Serial.printf("\n");
}

void listDir(fs::FS &fs, const char * dirname, uint8_t levels){
    LOGD("Listing directory: %s", dirname);

    File root = fs.open(dirname);
    if(!root){
        LOGD("- failed to open directory");
        return;
    }
    if(!root.isDirectory()){
        LOGD(" - not a directory");
        return;
    }

    File file = root.openNextFile();
    while(file){
        if(file.isDirectory()){
            LOGD_RAW("  DIR : ");
            LOGD_RAWLN(file.name());
            if(levels){
                listDir(fs, file.name(), levels -1);
            }
        } else {
            LOGD_RAW("  FILE: ");
            LOGD_RAW(file.name());
            LOGD_RAW("\tSIZE: ");
            LOGD_RAWLN(file.size());
        }
        file = root.openNextFile();
    }
}

String getContentType(String filename){
  if(server.hasArg("download")) return "application/octet-stream";
  else if(filename.endsWith(".htm")) return "text/html";
  else if(filename.endsWith(".html")) return "text/html";
  else if(filename.endsWith(".css")) return "text/css";
  else if(filename.endsWith(".js")) return "application/javascript";
  else if(filename.endsWith(".png")) return "image/png";
  else if(filename.endsWith(".gif")) return "image/gif";
  else if(filename.endsWith(".jpg")) return "image/jpeg";
  else if(filename.endsWith(".ico")) return "image/x-icon";
  else if(filename.endsWith(".xml")) return "text/xml";
  else if(filename.endsWith(".pdf")) return "application/x-pdf";
  else if(filename.endsWith(".zip")) return "application/x-zip";
  else if(filename.endsWith(".gz")) return "application/x-gzip";
  else if(filename.endsWith(".svg")) return "image/svg+xml";
  return "text/plain";
}

unsigned long getTime() {
  time_t now;
  struct tm timeinfo;
  if (!getLocalTime(&timeinfo)) {
    //Serial.println("Failed to obtain time");
    return(0);
  }
  time(&now);
  return now;
}

String renderLocalTime() {
  struct tm timeinfo;
  if(!getLocalTime(&timeinfo)){
    LOGW("Failed to obtain time");
    return "";
  }

  char timeStringBuff[50];
  strftime (timeStringBuff, 50,"%Y-%m-%dT%H:%M:%SZ", &timeinfo);
  String asString(timeStringBuff);
  return asString;
}

// ===== OPERATIONS

/**
 * Value is anything between 0 to 65535 representing 16 bits of data I/Os
 */
void operation_relay_set_internal(int value) {
   // take the latchPin low so 
   // the LEDs don't change while you're sending in bits:
   digitalWrite(latchPin, LOW);
   
   // shift out the highbyte
   shiftOut(dataPin, clockPin, MSBFIRST, (value >> 8));
   // shift out the lowbyte
   shiftOut(dataPin, clockPin, MSBFIRST, value);
   
   //take the latch pin high so the LEDs will light up:
   digitalWrite(latchPin, HIGH);
}

/**
 * Set Relay state to specified value 0, 1 or -1 for switch
 */
int operation_relay_set(int relayNb, int relayStateWanted) {
  // int relayStateWanted = -1;
  int thisRelayState = (relayState >> relayNb) & 1;
  int relayStateResponse = thisRelayState;
  
  LOGD("Relay %d(%d) => %d", relayNb, relayStateWanted, thisRelayState);

  // switch on
  if(thisRelayState == 0 && relayStateWanted != 0) {
    relayState |= (1 << relayNb);
    relayStateResponse = 1;
  }

  // switch off
  if(thisRelayState == 1 && relayStateWanted != 1) {
    relayState &= ~(1 << relayNb);
    relayStateResponse = 0;
  }
  
  LOGD("Relays = %d", relayState);
  operation_relay_set_internal(relayState);

  websocket_broadcast_relay(relayNb, relayStateResponse);
  return relayStateResponse;
}

/**
 * Tests all the relays, one by one with on/off
 */
void operation_test() {
  int pause = 500;  
  for (int switchId = 15; switchId >= 0; switchId--) {
    operation_relay_set(switchId, -1); 
    delay(pause);
    operation_relay_set(switchId, -1);
    delay(pause);
  }
}

/**
 * Reset all the relays to zero
 */
void operation_reset() {
  int pause = 500;  
  for (int switchId = 15; switchId >= 0; switchId--) {
    operation_relay_set(switchId, 0); 
    delay(pause);
  }
}

void operation_th() {
  lastTemperature = round(htu.readTemperature()*100)/100.0;
  lastHumidity = round(htu.readHumidity()*100)/100.0;
  LOGD("Temp=%.2f C° / Humidity=%.2f %%", lastTemperature, lastHumidity);
}

// ===== JSON

void json_system(JsonObject system) {
  system["chip-model"] = ESP.getChipModel();
  system["chip-revision"] = ESP.getChipRevision();
  system["chip-cores"] = ESP.getChipCores();
  String chipBL = String((chip_info.features & CHIP_FEATURE_BT) ? "/BT" : "") + String((chip_info.features & CHIP_FEATURE_BLE) ? "/BLE" : "");
  system["chip-bluetooth"] = chipBL;
  system["chip-id"] = chipId;
  system["heap"] = ESP.getFreeHeap();
  system["flash-size"] = ESP.getFlashChipSize()/1024;
  system["flash-type"] = String((chip_info.features & CHIP_FEATURE_EMB_FLASH) ? "embeded" : "external");
  system["time-iso"] = renderLocalTime();
}

void json_sensors(JsonObject sensors) {
  operation_th();
  sensors["temperature"] = lastTemperature;
  sensors["humidity"] = lastHumidity;
}

void json_relay(JsonObject relay, int switchId) {
  int thisRelayState = (relayState >> switchId) & 1;
  
  relay["description"] = sensors[switchId];
  relay["id"] = switchId;
  relay["value"] = thisRelayState;
}

void json_relays(JsonArray relays) {
  for (int switchId = 0; switchId < 16; switchId++) {
    JsonObject relay = relays.createNestedObject();
    json_relay(relay, switchId);
  }
}

String json_status(String message) {

  StaticJsonDocument<2048> doc;

  JsonObject system = doc.createNestedObject("system");
  json_system(system);
  
  if(isHTU21Found) {
    JsonObject sensors = doc.createNestedObject("sensors");
    json_sensors(sensors);
  }

  JsonArray relays = doc.createNestedArray("relays");
  json_relays(relays);

  JsonObject teleinfo = doc.createNestedObject("teleinfo");
  json_teleinfo(teleinfo);

  if(message != "") {
    doc["message"] = message;
  }
  
  String json;
  serializeJson(doc, json);
  return json;
}

// ===== CONTROLLERS

void controller_handleNotFound() {
  if(!controller_file_read(server.uri()))
    server.send(404, "text/plain","404: Not found");
}

bool controller_file_read(String path){
  LOGD("handleFileRead: %s", path.c_str());
  if(path.endsWith("/")) path += "index.htm";
  String contentType = getContentType(path);
  String pathWithGz = path + ".gz";
  if(LittleFS.exists(pathWithGz) || LittleFS.exists(path)){
    if(LittleFS.exists(pathWithGz))
      path += ".gz";
    File file = LittleFS.open(path, "r");
    size_t sent = server.streamFile(file, contentType);
    file.close();
    return true;
  }
  return false;
}

void controller_status() {
  String json = json_status("status");
  server.send(200, "application/json", json);
  json = String();
}

void controller_test() {
  server.send(200, "text/plain", "");
  operation_test();
}

void controller_relay_set() {
  if(!server.hasArg("id")) {
    return;
  }

  int relayWantedState = -1;
  if(server.hasArg("state")) {
    relayWantedState = server.arg("state").toInt();
  }
    
  int relayNb = server.arg("id").toInt();
  int relayState = operation_relay_set(relayNb, relayWantedState);

  String json = "{\n";
  json += "  \"id\": " + String(relayNb) + ", \"value\": " + String(relayState) + "\n";
  json += "}";
  
  server.send(200, "text/plain", json);
}

// ===== PROMETHEUS METRICS

void build_metrics_teleinfo(String &body) {
  ValueList * me = tinfo.getList();
  if (!me) return;

  while (me->next) {
    me = me->next;
    if (!me->value || !strlen(me->value)) continue;

    boolean isNumber = true;
    char * p = me->value;
    while (*p && isNumber) {
      if (*p < '0' || *p > '9') isNumber = false;
      p++;
    }

    String key = String("teleinfo_") + String(me->name);
    key.toLowerCase();
    key.replace("-", "_");
    key.replace(" ", "_");

    if (isNumber) {
      body += "# HELP " + key + " Teleinfo metric\n";
      body += "# TYPE " + key + " gauge\n";
      body += key + " " + String(atol(me->value)) + "\n";
    } else {
      body += "# HELP " + key + " Teleinfo info\n";
      body += "# TYPE " + key + " gauge\n";
      body += key + "{value=\"" + String(me->value) + "\"} 1\n";
    }
  }
}

void controller_metrics() {
  String body;

  // --- System
  body += "# HELP esp_heap_bytes Free heap memory\n";
  body += "# TYPE esp_heap_bytes gauge\n";
  body += "esp_heap_bytes " + String(ESP.getFreeHeap()) + "\n";

  body += "# HELP esp_uptime_seconds Device uptime\n";
  body += "# TYPE esp_uptime_seconds gauge\n";
  body += "esp_uptime_seconds " + String(millis() / 1000) + "\n";

  // --- Sensors
  if (isHTU21Found) {
    operation_th();
    body += "# HELP esp_temperature_celsius Temperature\n";
    body += "# TYPE esp_temperature_celsius gauge\n";
    body += "esp_temperature_celsius " + String(lastTemperature) + "\n";

    body += "# HELP esp_humidity_percent Relative humidity\n";
    body += "# TYPE esp_humidity_percent gauge\n";
    body += "esp_humidity_percent " + String(lastHumidity) + "\n";
  }

  // --- Relays
  body += "# HELP esp_relay_state Relay state (0=off, 1=on)\n";
  body += "# TYPE esp_relay_state gauge\n";
  for (int i = 0; i < 16; i++) {
    int state = (relayState >> i) & 1;
    body += "esp_relay_state{id=\"" + String(i) + "\",description=\"" + sensors[i] + "\"} " + String(state) + "\n";
  }

  // --- Teleinfo
  build_metrics_teleinfo(body);

  server.send(200, "text/plain; version=0.0.4", body);
}

// ===== TELEINFO

 /* ======================================================================
Function: printUptime 
Purpose : print pseudo uptime value
Input   : -
Output  : - 
Comments: compteur de secondes basique sans controle de dépassement
          En plus SoftwareSerial rend le compteur de millis() totalement
          A la rue, donc la precision de ce compteur de seconde n'est
          pas fiable du tout, dont acte !!!
====================================================================== */
void printUptime(void) {
  LOGD_RAW(String(millis()/1000) + "s\t");
}

/* ======================================================================
Function: ADPSCallback 
Purpose : called by library when we detected a ADPS on any phased
Input   : phase number 
            0 for ADPS (monophase)
            1 for ADIR1 triphase
            2 for ADIR2 triphase
            3 for ADIR3 triphase
Output  : - 
Comments: should have been initialised in the main sketch with a
          tinfo.attachADPSCallback(ADPSCallback())
====================================================================== */
void ADPSCallback(uint8_t phase) {
  printUptime();
#if LOG_LEVEL >= LOG_DEBUG
  if (phase == 0 ) {
    LOGD_RAWLN("ADPS");
  }
  else {
    LOGD_RAW("ADPS PHASE #");
    LOGD_RAWLN(String('0' + phase));
  }
#endif
}

/* ======================================================================
Function: DataCallback 
Purpose : callback when we detected new or modified data received
Input   : linked list pointer on the concerned data
          current flags value
Output  : - 
Comments: -
====================================================================== */
void DataCallback(ValueList * me, uint8_t  flags) {
  // Show our not accurate second counter
  printUptime();

  if (flags & TINFO_FLAGS_ADDED) 
    Serial.print(F("NEW -> "));

  if (flags & TINFO_FLAGS_UPDATED)
    Serial.print(F("MAJ -> "));

  // Display values
  Serial.print(me->name);
  Serial.print("=");
  Serial.println(me->value);

  websocket_broadcast_teleinfo(String(me->name), String(me->value));
}

/* ======================================================================
Function: NewFrame 
Purpose : callback when we received a complete teleinfo frame
Input   : linked list pointer on the concerned data
Output  : - 
Comments: -
====================================================================== */
void NewFrame(ValueList * me) {
  // Show our not accurate second counter
  printUptime();
  Serial.println(F("FRAME -> SAME AS PREVIOUS"));
}

/* ======================================================================
Function: NewFrame 
Purpose : callback when we received a complete teleinfo frame
Input   : linked list pointer on the concerned data
Output  : - 
Comments: it's called only if one data in the frame is different than
          the previous frame
====================================================================== */
void UpdatedFrame(ValueList * me) {
  // Show our not accurate second counter
  printUptime();
  Serial.println(F("FRAME -> UPDATED"));
}

/* ======================================================================
Function: render_teleinfo 
Purpose : dump teleinfo values as JSON
Output  : JSON
Comments: -
====================================================================== */
void json_teleinfo(JsonObject teleinfo) {
  ValueList * me = tinfo.getList();

  if (me) {
    // Loop thru the node
    while (me->next) {
      // go to next node
      me = me->next;

      // we have at least something ?
      if (me->value && strlen(me->value)) {
        boolean isNumber = true;
        uint8_t c;
        char * p = me->value;

        // check if value is number
        while (*p && isNumber) {
          if ( *p < '0' || *p > '9' )
            isNumber = false;
          p++;
        }

        // this will add "" on not number values
        if (!isNumber) {
          teleinfo[me->name] = me->value;
        }
        // this will remove leading zero on numbers
        else
          teleinfo[me->name] = atol(me->value);
      }
    }
  }
}

// ===== WEBSOCKET

void websocket_broadcast_relay(int relayNb, int relayStateResponse) {
    StaticJsonDocument<2048> doc;
    JsonArray relays = doc.createNestedArray("relays");

    JsonObject relay = relays.createNestedObject();
    relay["id"] = relayNb;
    relay["value"] = relayStateResponse;
    String json;
    serializeJson(doc, json);
    
    webSocket.broadcastTXT(json);
}

void websocket_broadcast_teleinfo(String key, String value) {
    StaticJsonDocument<2048> doc;
    JsonObject teleinfo = doc.createNestedObject("teleinfo");
    teleinfo[key] = value;
    String json;
    serializeJson(doc, json);
    
    webSocket.broadcastTXT(json);
}
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

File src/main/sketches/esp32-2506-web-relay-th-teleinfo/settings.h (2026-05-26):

// Webserver Config
#ifndef SECRET_SSID
#define SECRET_SSID "<ssid>"
#endif
#ifndef SECRET_PASS
#define SECRET_PASS "<password>"
#endif
const char *ssid = SECRET_SSID;
const char *password = SECRET_PASS;
const char* host = "ioteleinfo";

// NTP
const char* ntpServer = "pool.ntp.org";
const long  gmtOffset_sec = 0;
const int   daylightOffset_sec = 0;

//// PINS (74HC595) - ESP8266
//int latchPin = 15;
//int clockPin = 12;
//int dataPin = 13;

// PINS (74HC595) - ESP32
int latchPin = 5;
int clockPin = 19;
int dataPin = 23;

// #define ENABLE_HTU21D 0

// Relay Map
#define ARRAYSIZE 16
String sensors[ARRAYSIZE] = { "Ch. Jeux", "Bureau", "Ch. Lena", "Ch. Damien", "SdB Haut", "Mezanine", "Ch. Bas", "SdB Bas", "Portail", "NA", "NA", "NA", "NA", "NA", "Salon", "Hall" };

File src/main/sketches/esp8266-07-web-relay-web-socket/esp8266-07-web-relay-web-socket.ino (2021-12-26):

/* 
  ti-dhome - esp8266 base web relay board
  Copyright (c) 2022 Kalemena. All rights reserved.

  access the sample web page at http://iotrelays.local
  edit the page by going to http://iotrelays.local/edit
*/

#include <Arduino.h>

#include <ESP8266WiFi.h>
#include <ESP8266WiFiMulti.h>
#include <WebSockets4WebServer.h>
#include <Hash.h>
#include <ESP8266mDNS.h>
#include <LittleFS.h>
#include <ArduinoJson.h>

ESP8266WiFiMulti WiFiMulti;

ESP8266WebServer server(80);
WebSockets4WebServer webSocket;

// holds the current upload
File fsUploadFile;
// holds 16 bits
unsigned int relayState = 0;

extern "C" {
  #include "user_interface.h"
}

#define DEBUG true
#define Serial if(DEBUG)Serial

// ===== CONFIGURATION

#include "settings.h"

// ===== SETUP

void setup() {
    Serial.begin(115200);
    Serial.setDebugOutput(true);

    Serial.println();
    Serial.println("Initializing ...");
    Serial.println();

    for(uint8_t t = 4; t > 0; t--) {
        Serial.printf("[SETUP] BOOT WAIT %d...\n", t);
        Serial.flush();
        delay(1000);
    }

    // Setup file system
    if (LittleFS.begin()) {
      Serial.println(F("LittleFS system mounted with success"));
    } else {
      Serial.println(F("An Error has occurred while mounting LittleFS"));
    }
    
    // Get all information about LittleFS
    FSInfo fsInfo;
    LittleFS.info(fsInfo);
  
    Serial.println("------------------------------");
    Serial.println("File system info");
    Serial.println("------------------------------");
    Serial.printf("Total space:      %d byte\n", fsInfo.totalBytes);
    Serial.printf("Total space used: %d byte\n", fsInfo.usedBytes);
    Serial.printf("Block size:       %d byte\n", fsInfo.blockSize);
    Serial.printf("Page size:        %d byte\n", fsInfo.totalBytes);
    Serial.printf("Max open files:   %d\n", fsInfo.maxOpenFiles);
    Serial.printf("Max path lenght:  %d\n", fsInfo.maxPathLength);
  
    Serial.println("------------------------------");
    Serial.println("List files");
    Serial.println("------------------------------");
    Dir dirit = LittleFS.openDir("/");
    while (dirit.next()) {
      if (dirit.fileSize()) {
        String fileName = dirit.fileName();
        size_t fileSize = dirit.fileSize();
        Serial.printf(" - %s - %s byte\n", fileName.c_str(), String(fileSize).c_str());
      }
    }
    Serial.printf("\n");
    
    delay(10);

    // 74HC595
    // Set pins to output so you can control the shift register
    pinMode(latchPin, OUTPUT);
    pinMode(clockPin, OUTPUT);
    pinMode(dataPin, OUTPUT);

    Serial.println("WiFi initializing");
    WiFiMulti.addAP(ssid, password);

    while(WiFiMulti.run() != WL_CONNECTED) {
        delay(100);
        Serial.print(".");
    }

    Serial.println("Controller initializing");
    // list directory
    server.on("/list", HTTP_GET, controller_file_list);
    // file uploads at that location
    server.on("/edit", HTTP_POST, [](){ server.send(200, "text/plain", ""); }, controller_file_upload);
    // file create
    server.on("/edit", HTTP_PUT, controller_file_create);
    // file delete
    server.on("/edit", HTTP_DELETE, controller_file_delete);
    // load file editor
    server.on("/edit", HTTP_GET, [](){
      if(!controller_file_read("/edit.htm")) server.send(404, "text/plain", "FileNotFound");
    });

    // static files
    //server.serveStatic("/favicon.ico", LittleFS, "/favicon.ico");
    //server.serveStatic("/on.svg", LittleFS, "/on.svg");
    //server.serveStatic("/off.svg", LittleFS, "/off.svg");
    
    server.on("/", []() {
        // send index.html
        server.send(200, "text/html", "<html><head><meta http-equiv=\"refresh\" content=\"0; URL=/index.html\" /></head></html>");
    });
    server.on("/status", HTTP_GET, controller_status);
    server.on("/test", HTTP_GET, controller_test);
    server.on("/relays/set", HTTP_GET, controller_relay_set);

    //called when the url is not defined here
    //use it to load content from LittleFS
    server.onNotFound([](){
      if(!controller_file_read(server.uri()))
        server.send(404, "text/plain", "FileNotFound");
    });
    
    // web socket
    server.addHook(webSocket.hookForWebserver("/ws", websocket_event));

    server.begin();
    
    Serial.println();
    Serial.print("Connected to ");
    Serial.println(ssid);
    Serial.print("IP address: ");
    Serial.println(WiFi.localIP());

    Serial.println("Connect as http://" + String(host) + ".local or http://" + WiFi.localIP().toString().c_str());
    Serial.print("Open http://"); Serial.print(host); Serial.println(" to see relays status");
    Serial.print("Open http://"); Serial.print(host); Serial.println(".local/edit to see the file browser");

    if (MDNS.begin(host)) {
        Serial.println("MDNS responder started");
    } else {
        Serial.println("MDNS.begin failed");
    }

    // Add service to MDNS
    MDNS.addService("http", "tcp", 80);

    delay(10);
    
    // reset to 0
    operation_relay_set_internal(0);
}

void loop() {
    server.handleClient();
    webSocket.loop();
    MDNS.update();
}

// ===== UTILITIES

String formatBytes(size_t bytes){
  if (bytes < 1024){
    return String(bytes)+"B";
  } else if(bytes < (1024 * 1024)){
    return String(bytes/1024.0)+"KB";
  } else if(bytes < (1024 * 1024 * 1024)){
    return String(bytes/1024.0/1024.0)+"MB";
  } else {
    return String(bytes/1024.0/1024.0/1024.0)+"GB";
  }
}

String getContentType(String filename){
  if(server.hasArg("download")) return "application/octet-stream";
  else if(filename.endsWith(".htm")) return "text/html";
  else if(filename.endsWith(".html")) return "text/html";
  else if(filename.endsWith(".css")) return "text/css";
  else if(filename.endsWith(".js")) return "application/javascript";
  else if(filename.endsWith(".png")) return "image/png";
  else if(filename.endsWith(".gif")) return "image/gif";
  else if(filename.endsWith(".jpg")) return "image/jpeg";
  else if(filename.endsWith(".ico")) return "image/x-icon";
  else if(filename.endsWith(".xml")) return "text/xml";
  else if(filename.endsWith(".pdf")) return "application/x-pdf";
  else if(filename.endsWith(".zip")) return "application/x-zip";
  else if(filename.endsWith(".gz")) return "application/x-gzip";
  else if(filename.endsWith(".svg")) return "image/svg+xml";
  return "text/plain";
}

// Utility convert String to Char
char* StringToChar(String s) {
  unsigned int bufSize = s.length() + 1; //String length + null terminator
  char* ret = new char[bufSize];
  s.toCharArray(ret, bufSize);
  return ret;
}

// ===== OPERATIONS
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

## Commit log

2016-10-26 Update BOM
2016-10-26 Resources: led blink
2016-10-26 More details on Wifi LED sample
2016-10-27 Explain wiring
2016-10-28 NodeMCU breadboard wires
    [web-relay-board-nodemcu.fzz]
2016-10-28 Basic relay sketch
2016-11-22 Fritzing board
    [web-relay-board-nodemcu-pcb.fzz]
2017-01-11 PCB update
    [web-relay-board-nodemcu-pcb.fzz]
2017-01-21 Relay board in place
2017-01-21 Update web relay board in place
2017-01-21 Add relay board PCB1
2019-03-01 move files up
    [web-relay-board-nodemcu-pcb-36.fzz]
2020-01-19 Refresh wiring ESP8266 to relays
2020-01-19 Refresh PCB details
2020-01-19 Remove useless fritzing
    [web-relay-board-nodemcu-pcb-36.fzz]
2021-01-25 07-web-relay-web-socket - base code
2021-01-25 esp8266-07-web-relay-web-socket - add status controller
2021-01-25 Sketch 07 Web-socket add code from 05
2021-01-26 Add parameter state=0-1 on /switch
2021-01-26 esp8266-07-web-relay-web-socket: add ws control
2021-01-26 esp8266-07-web-relay-web-socket: move websocket to data HTML file
2021-01-27 esp8266-07-web-relay-web-socket: fix controller status
    [esp8266-07-web-relay-web-socket.ino]
2021-01-27 esp8266-07-web-relay-web-socket: fix full /status
    [esp8266-07-web-relay-web-socket.ino]
2021-01-27 esp8266-07-web-relay-web-socket: sortof websocket ok
2021-01-28 esp8266-07-web-relay-web-socket: cleanup
2021-01-28 esp8266-07-web-relay-web-socket: websocket ok
2021-01-29 esp8266-06-web-relay-teleinfo: switch to LittleFS
2021-01-29 esp8266-07-web-relay-web-socket: add relay test()
2021-01-30 esp8266-07-web-relay-web-socket: ws reconnect
2021-01-30 esp8266-07-web-relay-web-socket: fix table re-populate
2021-01-30 esp8266-07-web-relay-web-socket: fix REST API
    [esp8266-07-web-relay-web-socket.ino]
2021-01-31 esp8266-07-web-relay-web-socket: docs
2021-02-01 esp8266-08-web-relay-th-teleinfo: add temp/humi
2021-02-01 esp8266-08-web-relay-th-teleinfo: add temp/humi websocket
2021-02-01 esp8266-08-web-relay-th-teleinfo: client with temp/humi
2021-02-02 esp8266-08-web-relay-th-teleinfo: doc HTU21
2021-02-05 ESP32 base code (WiFi sample for now)
2021-02-05 esp32-09-web-relay-th: add SPIFFS
2021-02-05 esp32-09-web-relay-th: add HTU21
2021-02-07 ESP32: Add relays operation
2021-02-07 ESP32 - add websocket
2021-02-08 ESP32: add WebServer on port 80
2021-02-08 ESP32: Add web page - OK
2021-02-09 ESP32: add REST responses
2021-02-09 ESP32: add mDNS
2021-02-13 ESP32: broadcast teleinfo
2021-02-14 ESP32: Teleinfo display
2021-02-14 ESP32: add teleinfo table
2021-02-14 ESP32: Teleinfo custom pin
2021-02-15 ESP32: add update teleinfo websocket
2021-02-15 ESP32: render status with including teleinfo
2021-02-15 ESP32: add system info
2021-02-16 ESP32: fix typo JSON
    [esp32-10-web-relay-th-teleinfo.ino]
2021-02-16 ESP32: update interface
2021-02-17 ESP32: docs
2021-02-17 ESP32: add NTP time
2021-02-17 ESP32: websocket NTP
2021-02-18 ESP32: UI time
2021-02-18 ESP32: Cleanup code
2021-02-19 ESP32: trying ArduinoJson lib
2021-02-19 ESP32: json_relay
2021-02-20 ESP32: simplify index.html
2021-02-20 ESP32: simplified websocket contract
2021-02-21 ESP32: add heap info to websocket
2021-02-26 3D: clip rail din
    [web-relay-din-clip.scad]
2021-02-27 3D: webrelay clip din
    [web-relay-din-clip.scad]
2021-02-27 3D: webrelay din clip
    [web-relay-din-clip.scad, web-relay-din-clip.stl]
2022-10-06 fix sample
2026-06-10 Docs - arduino-cli tips
2026-06-10 Sketch - ESP32 samples
